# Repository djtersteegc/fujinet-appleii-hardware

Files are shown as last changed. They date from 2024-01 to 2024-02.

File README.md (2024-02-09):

Hardware variants for the Apple II FujiNet platform (FujiApple).

Still a work in progress...

# DevKit IDC-20

Interactive BOM - [https://djtersteegc.github.io/fujinet-appleii-hardware/ibom-DevKit-IDC-20-v1.0.html](https://djtersteegc.github.io/fujinet-appleii-hardware/ibom-DevKit-IDC-20-v1.0.html)

# DevKit SmartPort

Interactive BOM - [https://djtersteegc.github.io/fujinet-appleii-hardware/ibom-DevKit-SmartPort-v1.0.html](https://djtersteegc.github.io/fujinet-appleii-hardware/ibom-DevKit-SmartPort-v1.0.html)

# DevKit Combo

Interactive BOM - [https://djtersteegc.github.io/fujinet-appleii-hardware/ibom-DevKit-Combo-v1.0.html](https://djtersteegc.github.io/fujinet-appleii-hardware/ibom-DevKit-Combo-v1.0.html)

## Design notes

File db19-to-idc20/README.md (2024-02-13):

Complete docs soon...

Bulk pins - https://www.aliexpress.us/item/3256802431271655.html

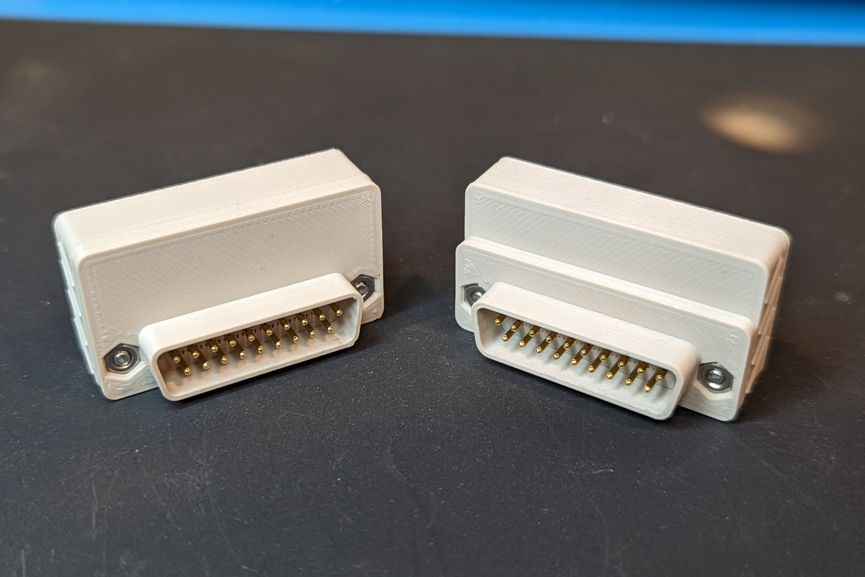
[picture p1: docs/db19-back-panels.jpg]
db19-back-panels


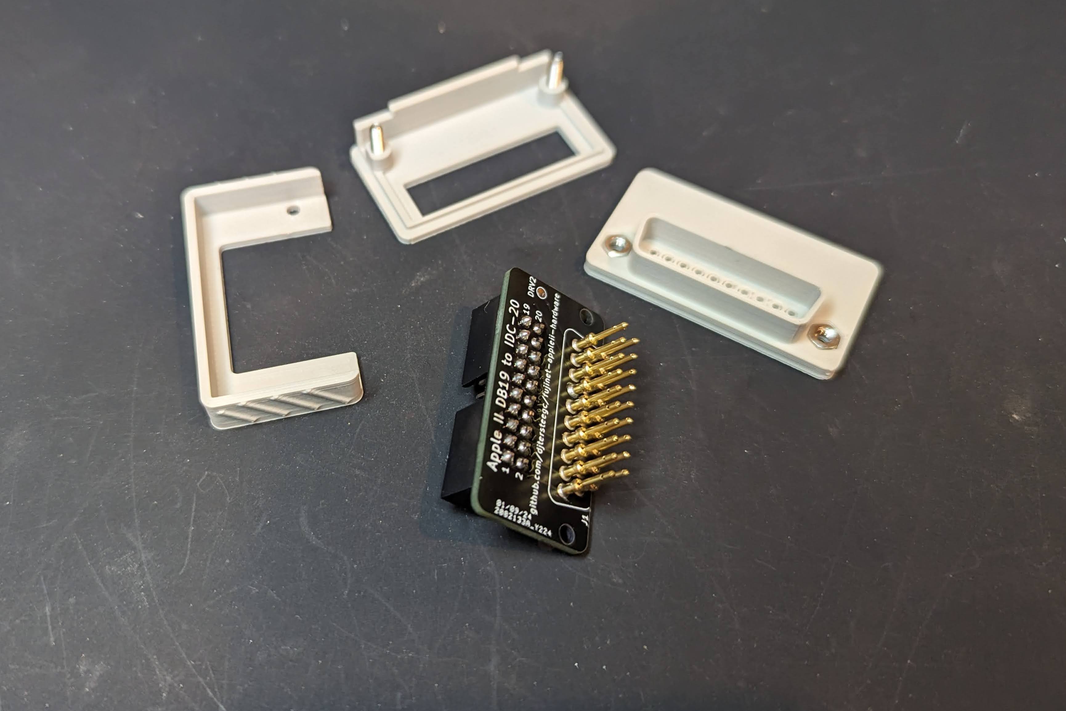
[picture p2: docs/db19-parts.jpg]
db19-parts


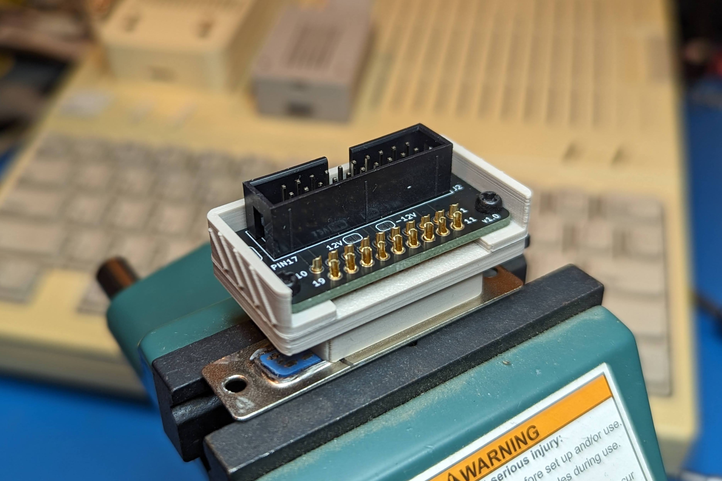
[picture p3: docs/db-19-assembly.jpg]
db-19-assembly


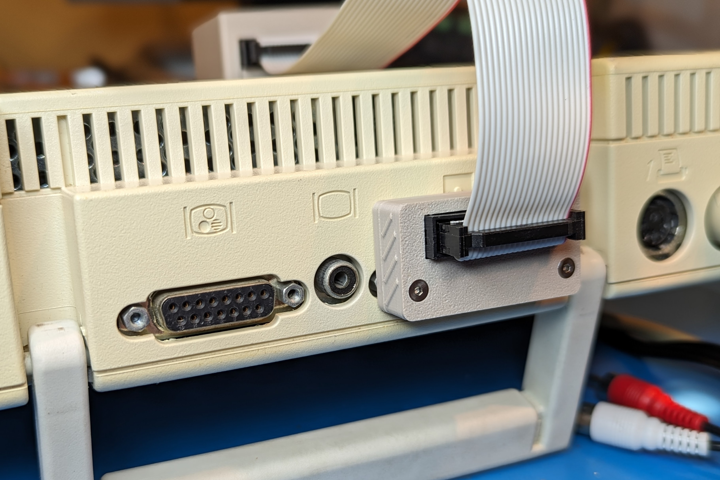
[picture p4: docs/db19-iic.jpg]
db19-iic


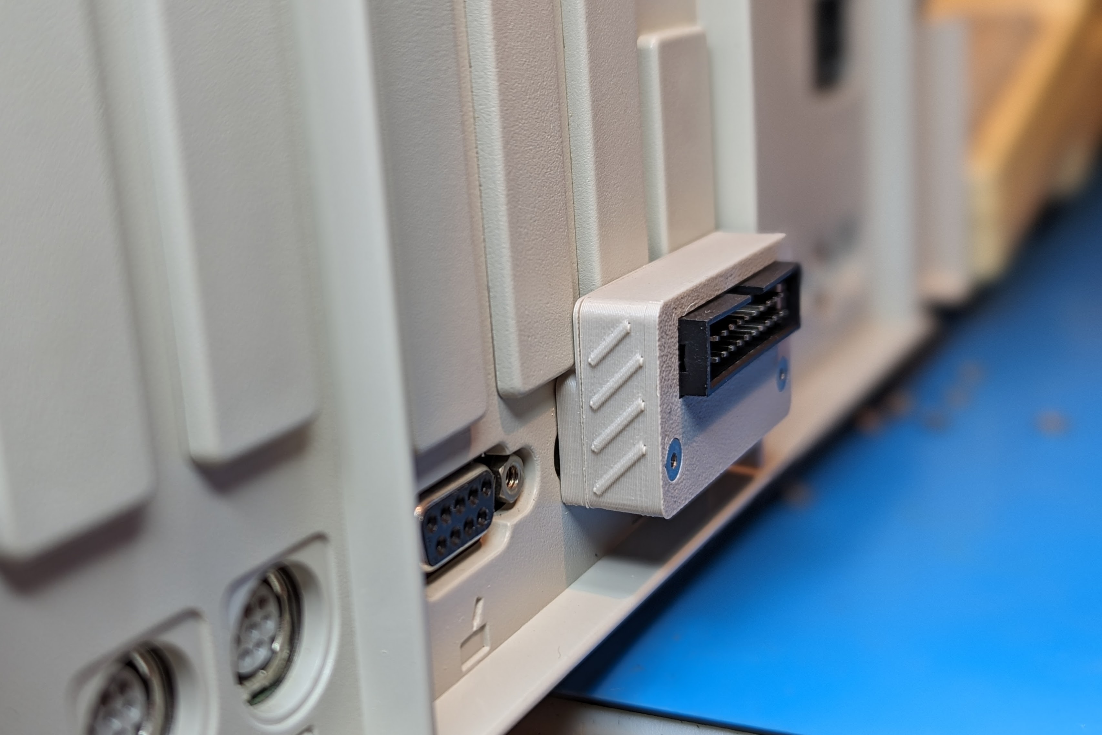
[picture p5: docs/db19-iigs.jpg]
db19-iigs


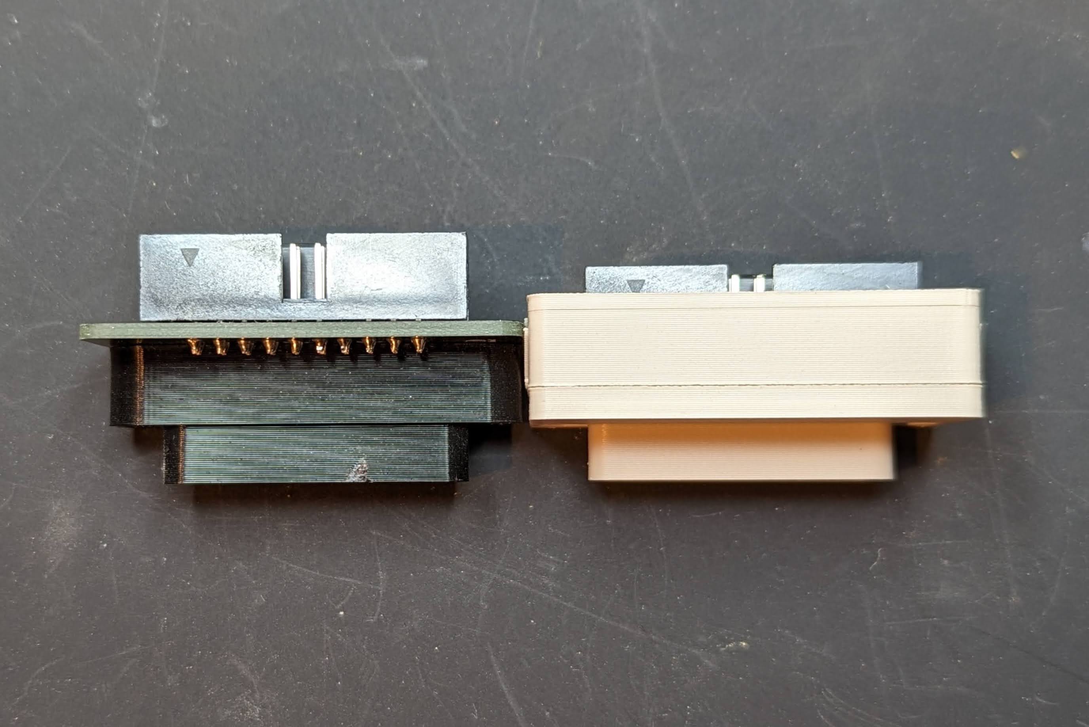
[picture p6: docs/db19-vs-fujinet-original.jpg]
db19-vs-fujinet-original


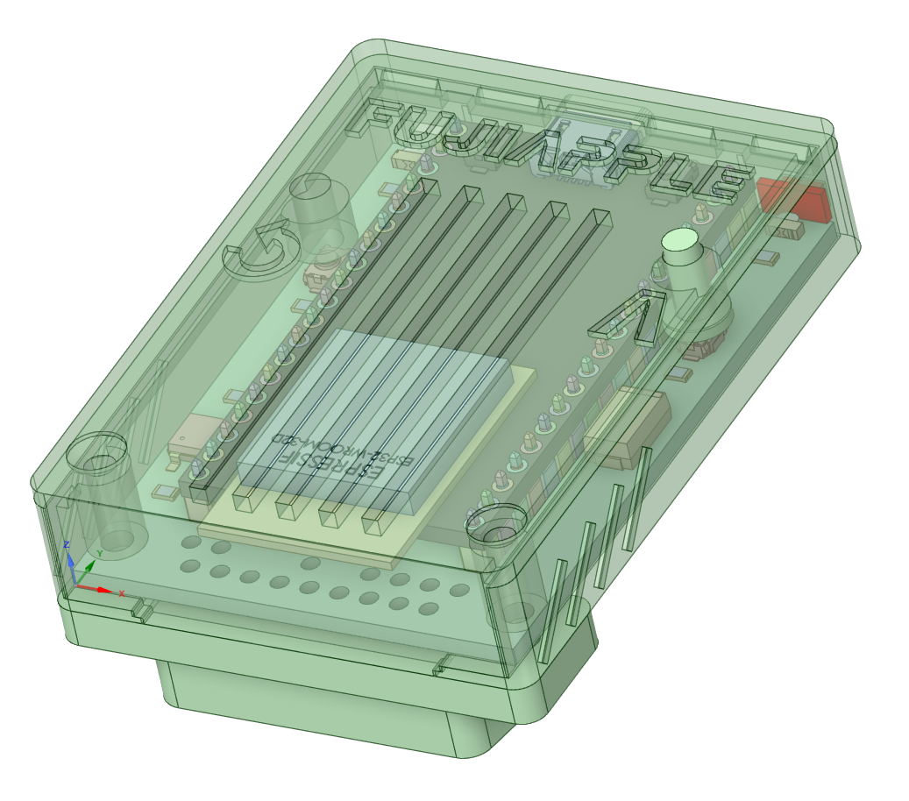
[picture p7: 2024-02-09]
docs/DesignSpark-SmartPort.PNG

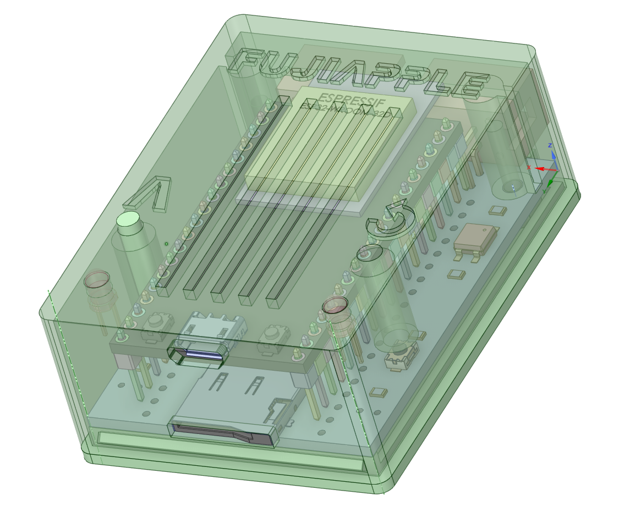
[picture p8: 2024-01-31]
docs/DesignSpark-IDC-20.PNG

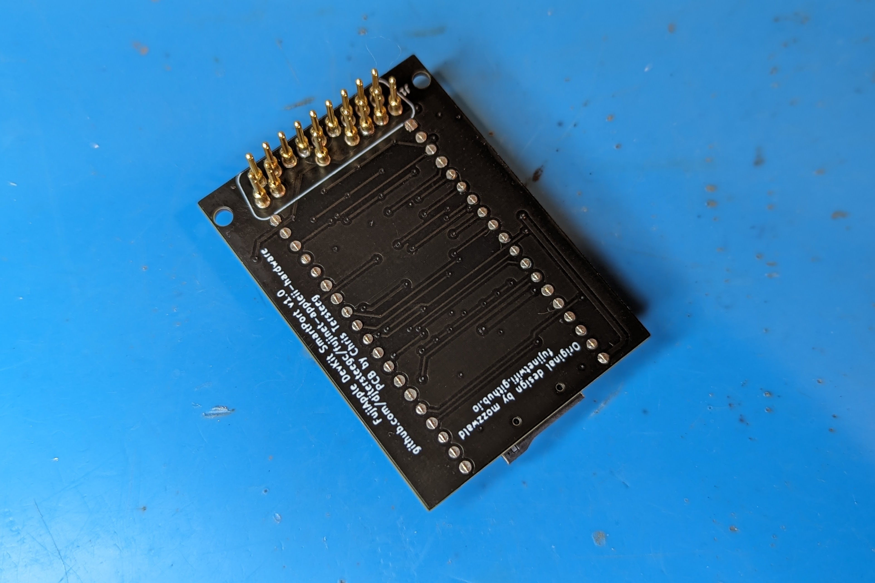
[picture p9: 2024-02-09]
docs/SmartPort-Flush-Cutters.jpg

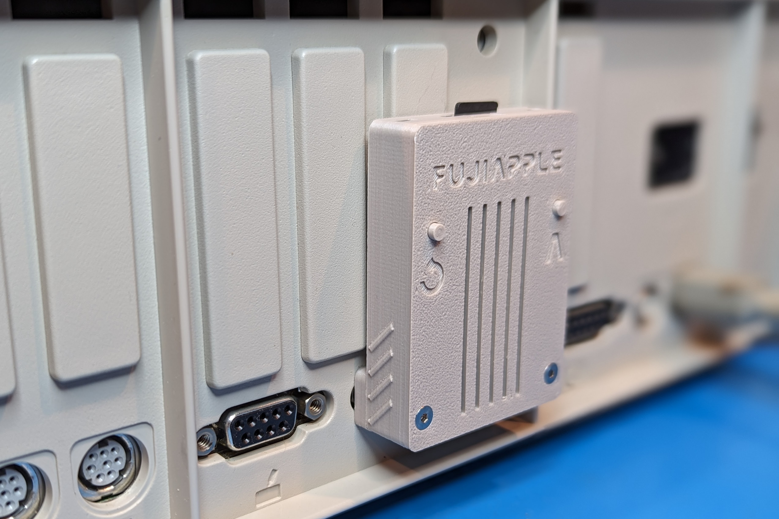
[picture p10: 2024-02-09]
docs/SmartPort-IIGS-Side.jpg

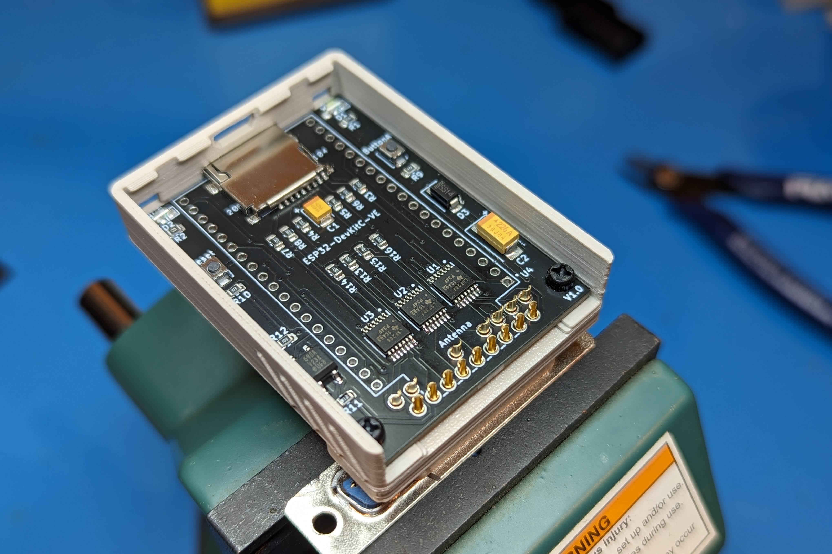
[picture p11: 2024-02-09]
docs/SmartPort-Connector.jpg

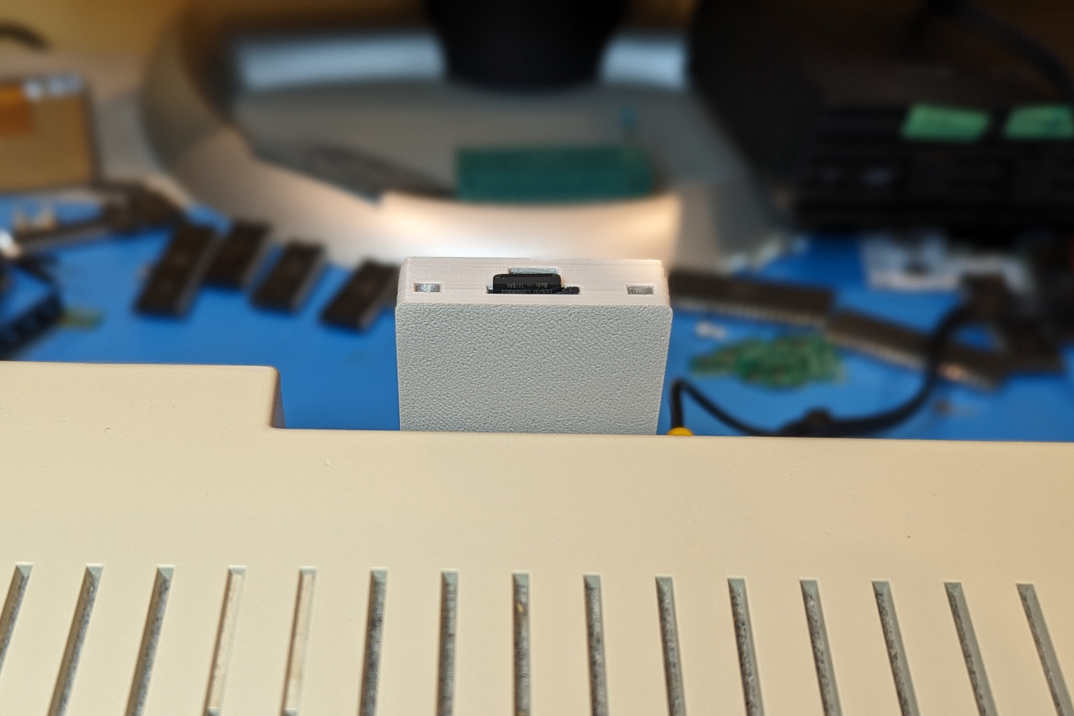
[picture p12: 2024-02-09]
docs/SmartPort-IIC-Front.jpg

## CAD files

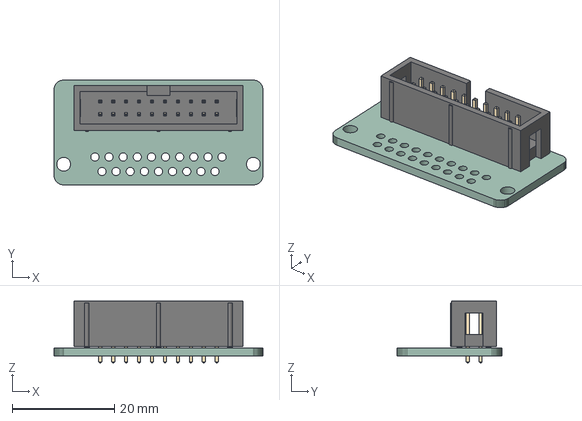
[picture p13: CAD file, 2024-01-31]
db19-to-idc20/3D/STEP/db19-to-idc20.step
41.0 x 20.6 x 12.1 mm
IDC_Header_2x10_P254mm_Vertical
db19-to-idc20 PCB

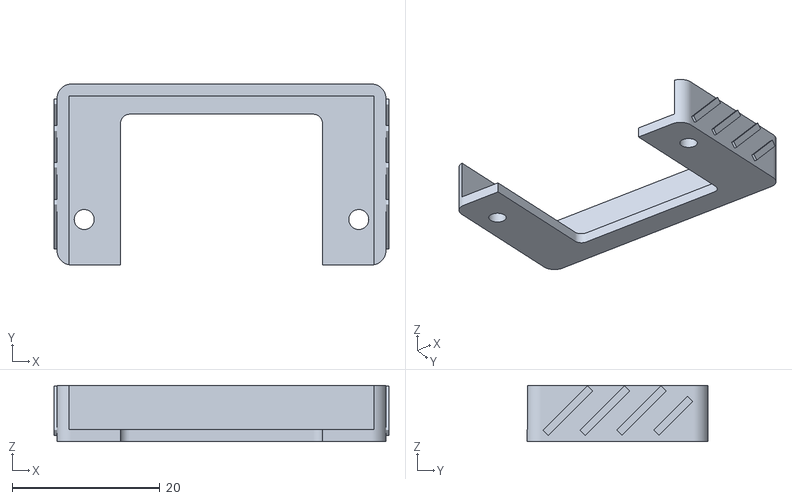
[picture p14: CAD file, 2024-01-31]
db19-to-idc20/3D/STL/db19-to-idc20-body.stl
45.4 x 24.5 x 7.60

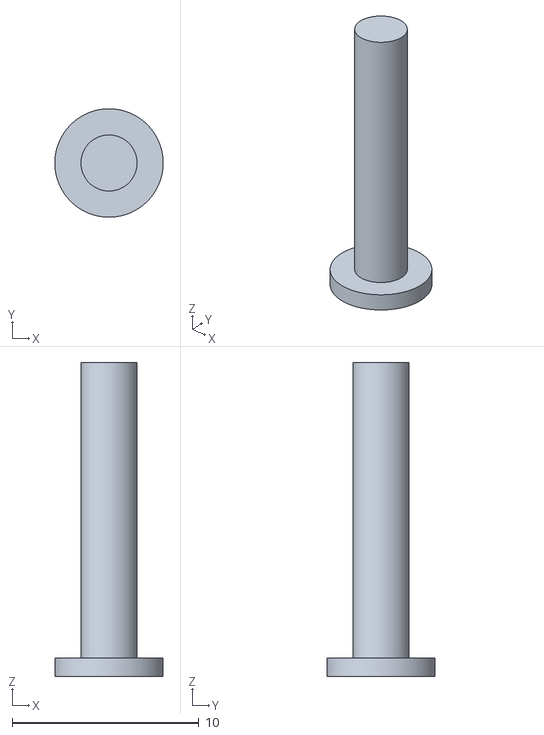
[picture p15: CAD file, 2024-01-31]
FujiApple-DevKit-IDC-20/3D/Tall/STL/FujiApple-DevKit-IDC-20-Tall-Button.stl
5.80 x 5.80 x 16.8

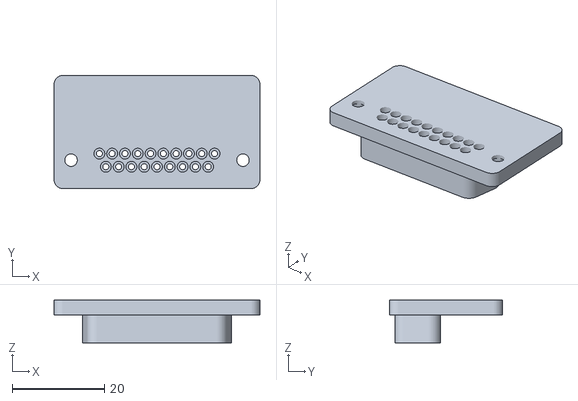
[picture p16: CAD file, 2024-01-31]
db19-to-idc20/3D/STL/db19-to-idc20-db19.stl
44.6 x 24.5 x 9.20

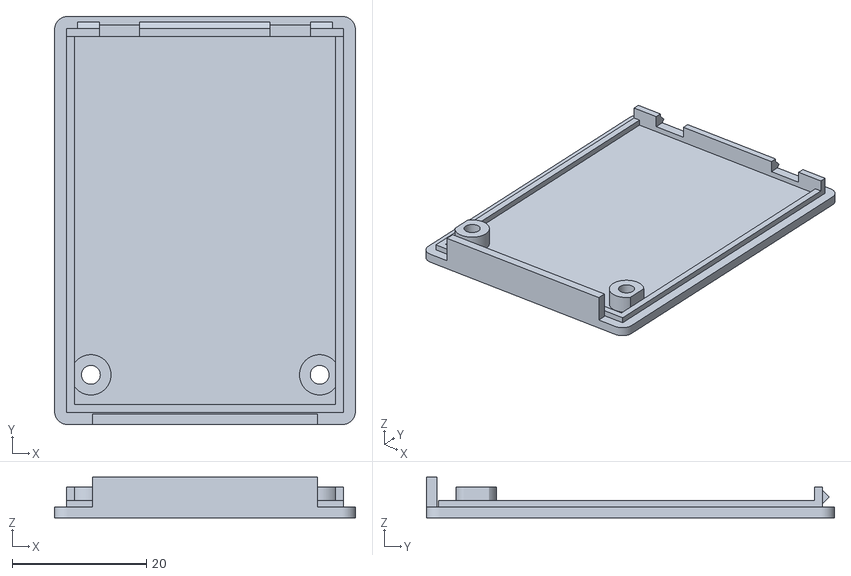
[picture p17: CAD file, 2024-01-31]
FujiApple-DevKit-IDC-20/3D/Tall/STL/FujiApple-DevKit-IDC-20-Tall-Lid.stl
44.8 x 60.7 x 6.09

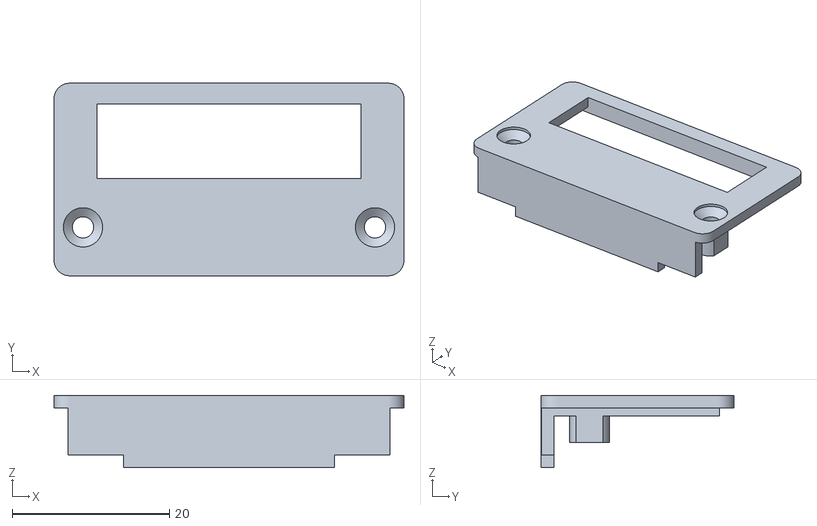
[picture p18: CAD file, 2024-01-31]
db19-to-idc20/3D/STL/db19-to-idc20-lid.stl
44.6 x 24.5 x 9.20

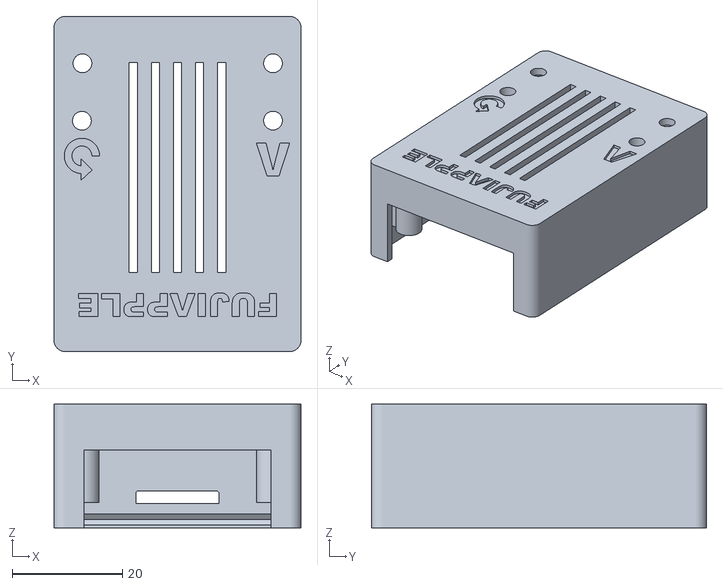
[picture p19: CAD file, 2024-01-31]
FujiApple-DevKit-IDC-20/3D/Tall/STL/FujiApple-DevKit-IDC-20-Tall-Body.stl
44.8 x 60.7 x 22.4

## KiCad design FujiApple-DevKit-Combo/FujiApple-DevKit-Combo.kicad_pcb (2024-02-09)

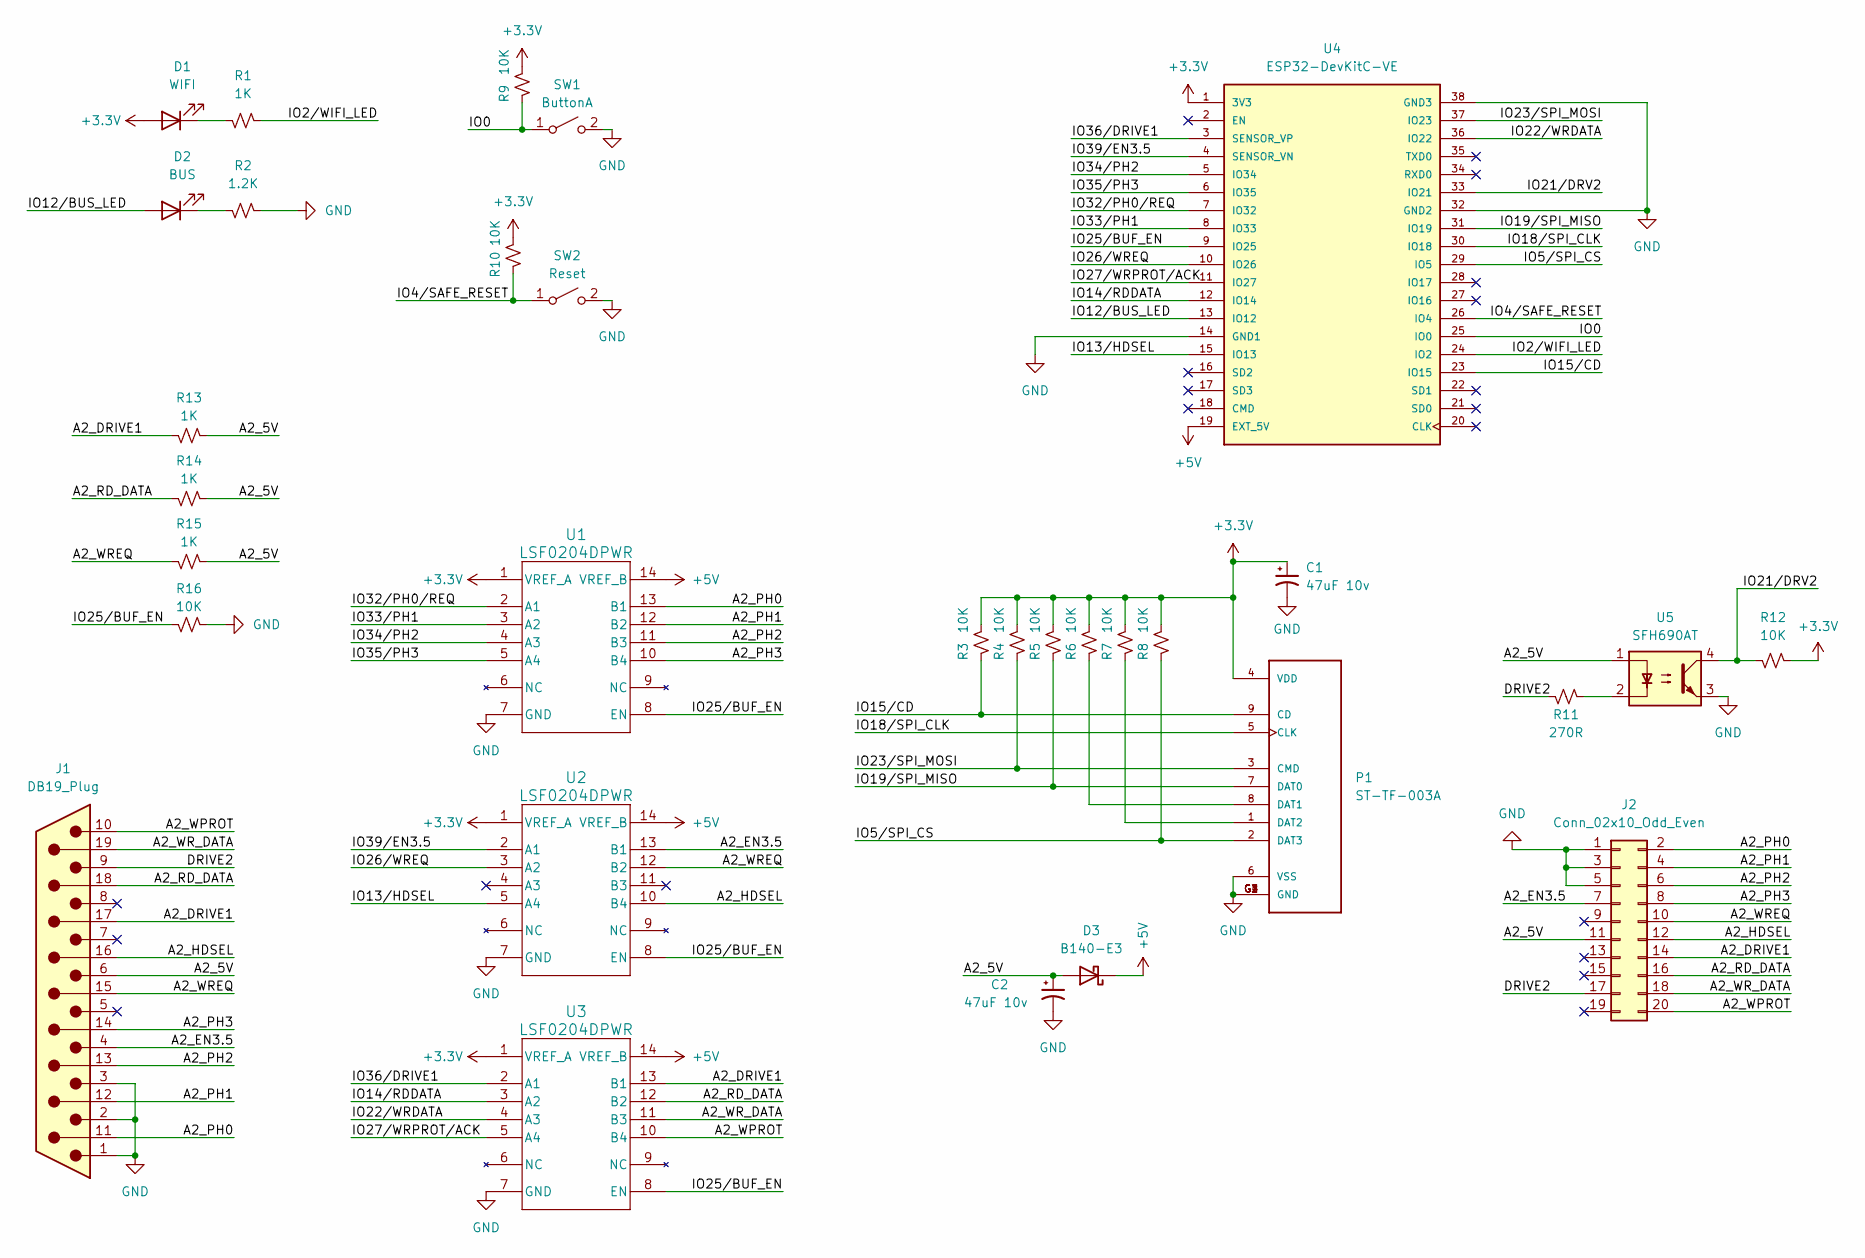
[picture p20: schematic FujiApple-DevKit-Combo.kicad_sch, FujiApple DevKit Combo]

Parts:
C1: 47uF 10v; CP_EIA-3528-15_AVX-H_Pad1.50x2.35mm_HandSolder
C2: 47uF 10v; CP_EIA-7343-30_AVX-N_Pad2.25x2.55mm_HandSolder
D1: WIFI; 1204 Side Emitting LED
D2: BUS; 1204 Side Emitting LED
D3: B140-E3; D_SMA
J1: DB19_Plug; DSUB-19_Male_Vertical_P2.77x2.84mm_Narrow_MountingHoles_Ful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
J2: Conn_02x10_Odd_Even; IDC-Header_2x10_P2.54mm_Vertical
P1: ST-TF-003A; SUNTECH_ST-TF-003A
R1, R13, R14, R15: 1K; R_0805_2012Metric_Pad1.20x1.40mm_HandSolder
R2: 1.2K; R_0805_2012Metric_Pad1.20x1.40mm_HandSolder
R3, R4, R5, R6, R7, R8, R9, R10, R12, R16: 10K; R_0805_2012Metric_Pad1.20x1.40mm_HandSolder
R11: 270R; R_0805_2012Metric_Pad1.20x1.40mm_HandSolder
SW1: ButtonA; SW_Push_SPST_NO_Alps_SKRK
SW2: Reset; SW_Push_SPST_NO_Alps_SKRK
U1, U2, U3: LSF0204DPWR; TSSOP-14_4.4x5mm_P0.65mm
U4: ESP32-DevKitC-VE; MODULE_ESP32-DEVKITC-32U; PARTREV N/A
U5: SFH690AT; SO-4_4.4x3.9mm_P2.54mm

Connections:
+3.3V: C1.1, D1.2 (A), P1.4 (VDD), R3.2, R4.2, R5.2, R6.2, R7.2, R8.2, R9.2, R10.2, R12.2, U1.1 (VREF_A), U2.1 (VREF_A), U3.1 (VREF_A), U4.1 (3V3)
+5V: D3.1 (K), U1.14 (VREF_B), U2.14 (VREF_B), U3.14 (VREF_B), U4.19 (EXT_5V)
/A2_5V: C2.1, D3.2 (A), J1.6, J2.11, R13.2, R14.2, R15.2, U5.1
/A2_DRIVE1: J1.17, J2.14, R13.1, U3.13 (B1)
/A2_EN3.5: J1.4, J2.7, U2.13 (B1)
/A2_HDSEL: J1.16, J2.12, U2.10 (B4)
/A2_PH0: J1.11, J2.2, U1.13 (B1)
/A2_PH1: J1.12, J2.4, U1.12 (B2)
/A2_PH2: J1.13, J2.6, U1.11 (B3)
/A2_PH3: J1.14, J2.8, U1.10 (B4)
/A2_RD_DATA: J1.18, J2.16, R14.1, U3.12 (B2)
/A2_WPROT: J1.10, J2.20, U3.10 (B4)
/A2_WREQ: J1.15, J2.10, R15.1, U2.12 (B2)
/A2_WR_DATA: J1.19, J2.18, U3.11 (B3)
/DRIVE2: J1.9, J2.17, R11.1
/IO0: R9.1, SW1.1 (A), U4.25 (IO0)
/IO2/WIFI_LED: R1.2, U4.24 (IO2)
/IO4/SAFE_RESET: R10.1, SW2.1 (A), U4.26 (IO4)
/IO5/SPI_CS: P1.2 (DAT3), R8.1, U4.29 (IO5)
/IO12/BUS_LED: D2.2 (A), U4.13 (IO12)
/IO13/HDSEL: U2.5 (A4), U4.15 (IO13)
/IO14/RDDATA: U3.3 (A2), U4.12 (IO14)
/IO15/CD: P1.9 (CD), R3.1, U4.23 (IO15)
/IO18/SPI_CLK: P1.5 (CLK), U4.30 (IO18)
/IO19/SPI_MISO: P1.7 (DAT0), R5.1, U4.31 (IO19)
/IO21/DRV2: R12.1, U4.33 (IO21), U5.4
/IO22/WRDATA: U3.4 (A3), U4.36 (IO22)
/IO23/SPI_MOSI: P1.3 (CMD), R4.1, U4.37 (IO23)
/IO25/BUF_EN: R16.1, U1.8 (EN), U2.8 (EN), U3.8 (EN), U4.9 (IO25)
/IO26/WREQ: U2.3 (A2), U4.10 (IO26)
/IO27/WRPROT/ACK: U3.5 (A4), U4.11 (IO27)
/IO32/PH0/REQ: U1.2 (A1), U4.7 (IO32)
/IO33/PH1: U1.3 (A2), U4.8 (IO33)
/IO34/PH2: U1.4 (A3), U4.5 (IO34)
/IO35/PH3: U1.5 (A4), U4.6 (IO35)
/IO36/DRIVE1: U3.2 (A1), U4.3 (SENSOR_VP)
/IO39/EN3.5: U2.2 (A1), U4.4 (SENSOR_VN)
GND: C1.2, C2.2, J1.1, J1.2, J1.3, J2.1, J2.3, J2.5, P1.6 (VSS), P1.G1 (GND), P1.G2 (GND), P1.G3 (GND), P1.G4 (GND), R2.2, R16.2, SW1.2 (B), SW2.2 (B), U1.7 (GND), U2.7 (GND), U3.7 (GND), U4.14 (GND1), U4.32 (GND2), U4.38 (GND3), U5.3
unnamed: D1.1 (K), R1.1
unnamed: D2.1 (K), R2.1
unnamed: P1.8 (DAT1), R6.1
unnamed: P1.1 (DAT2), R7.1
unnamed: R11.2, U5.2

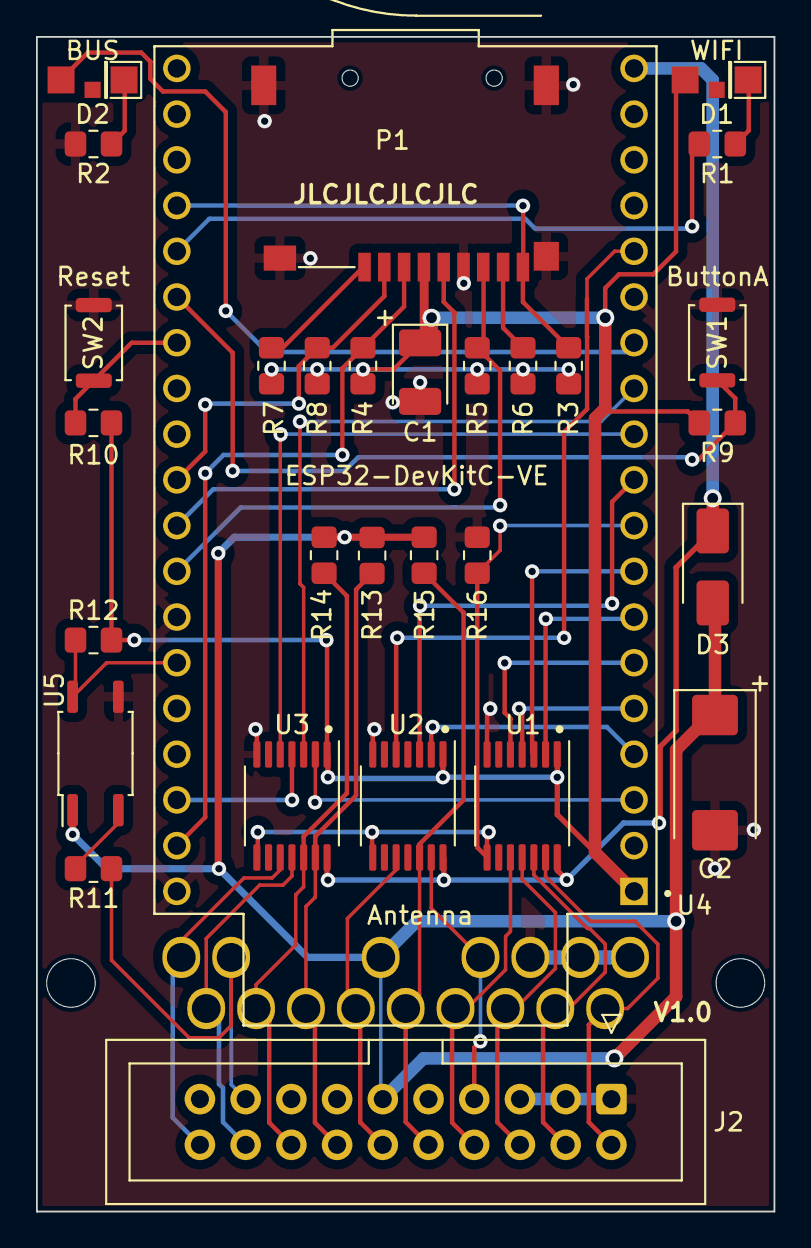
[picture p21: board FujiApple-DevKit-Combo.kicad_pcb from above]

Board: 2 copper layers, 41.0 x 65.3 mm, 31 parts (1 on the bottom side), 43 nets.

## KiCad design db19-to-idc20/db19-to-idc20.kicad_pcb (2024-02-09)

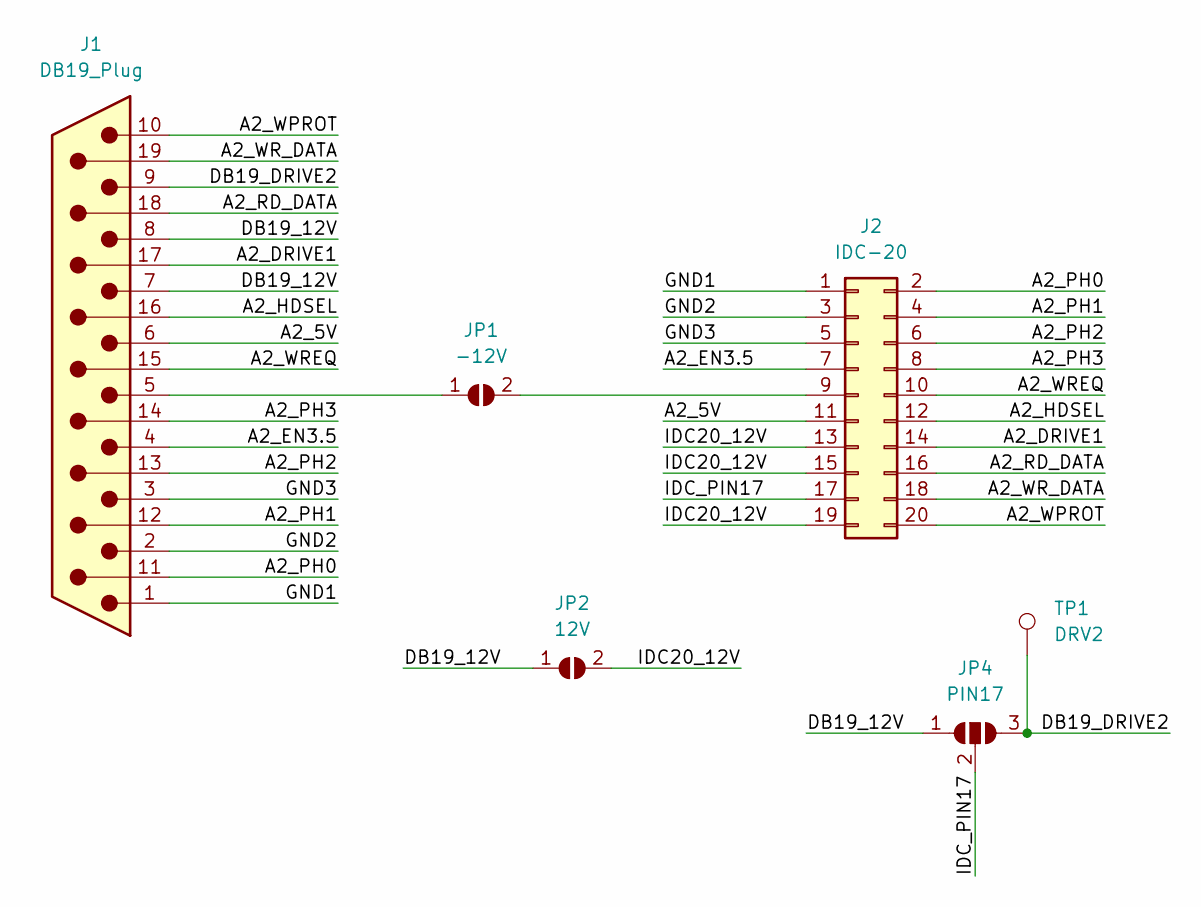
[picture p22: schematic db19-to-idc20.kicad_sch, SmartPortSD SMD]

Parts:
J1: DB19_Plug; DSUB-19_Male_Vertical_P2.77x2.84mm_Narrow_MountingHoles_Ful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
J2: IDC-20; IDC-Header_2x10_P2.54mm_Vertical
JP1: -12V; SolderJumper-2_P1.3mm_Open_RoundedPad1.0x1.5mm
JP2: 12V; SolderJumper-2_P1.3mm_Open_RoundedPad1.0x1.5mm
JP4: PIN17; SolderJumper-3_P1.3mm_Open_RoundedPad1.0x1.5mm_NumberLabels
TP1: DRV2; TestPoint_Pad_D1.5mm

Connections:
/A2_5V: J1.6, J2.11
/A2_DRIVE1: J1.17, J2.14
/A2_EN3.5: J1.4, J2.7
/A2_HDSEL: J1.16, J2.12
/A2_PH0: J1.11, J2.2
/A2_PH1: J1.12, J2.4
/A2_PH2: J1.13, J2.6
/A2_PH3: J1.14, J2.8
/A2_RD_DATA: J1.18, J2.16
/A2_WPROT: J1.10, J2.20
/A2_WREQ: J1.15, J2.10
/A2_WR_DATA: J1.19, J2.18
/DB19_12V: J1.7, J1.8, JP2.1 (A), JP4.1 (A)
/DB19_DRIVE2: J1.9, JP4.3 (B), TP1.1
/GND1: J1.1, J2.1
/GND2: J1.2, J2.3
/GND3: J1.3, J2.5
/IDC20_12V: J2.13, J2.15, J2.19, JP2.2 (B)
/IDC_PIN17: J2.17, JP4.2 (C)
unnamed: J2.9, JP1.2 (B)
unnamed: J1.5, JP1.1 (A)

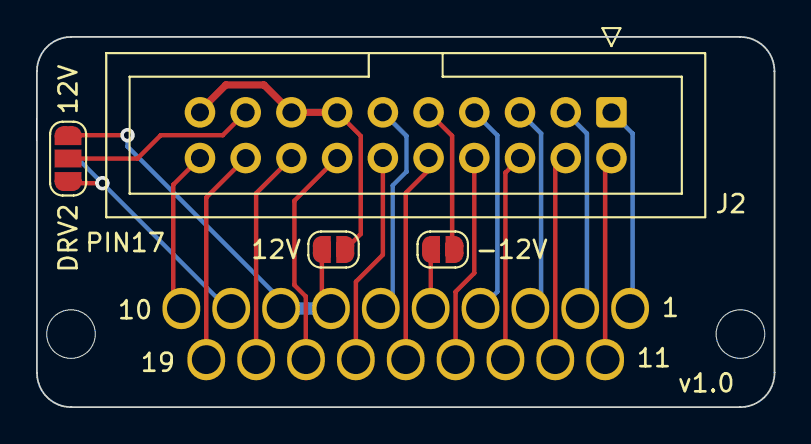
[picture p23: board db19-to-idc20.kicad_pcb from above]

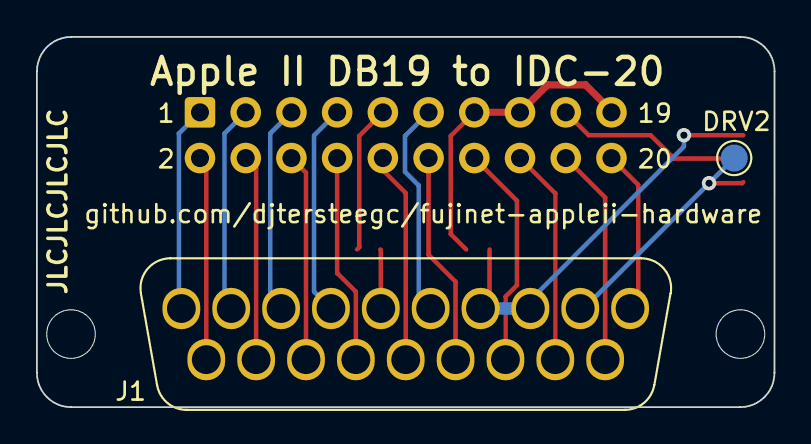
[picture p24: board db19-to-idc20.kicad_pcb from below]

Board: 2 copper layers, 41.0 x 20.6 mm, 6 parts (2 on the bottom side), 21 nets.

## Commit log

2024-01-10 V1.0 sent to the fab
    [FujiApple-DevKit-IDC-20-B_Cu.gbr, FujiApple-DevKit-IDC-20-B_Mask.gbr, FujiApple-DevKit-IDC-20-B_Paste.gbr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]
2024-01-31 Update 3D models and STL's. IDC-20 and DB19 adapter built and working.
    [FujiApple-DevKit-IDC-20-Tall-Body.stl, FujiApple-DevKit-IDC-20-Tall-Button.stl, FujiApple-DevKit-IDC-20-Tall-Lid.stl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]
2024-02-09 Add Combo version
    [FujiApple-DevKit-Combo-B_Cu.gbr, FujiApple-DevKit-Combo-B_Mask.gbr, FujiApple-DevKit-Combo-B_Paste.gbr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]
